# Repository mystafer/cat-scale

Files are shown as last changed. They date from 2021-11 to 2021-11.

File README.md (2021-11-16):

# Arduino Cat Scale

This project performs ongoing scale recordings of a litter box to track when a cat uses it, for how long, and their current weight. The data will hopefully be useful to predict health issues as cats' weight change.  It is designed to work with multiple cats using a custom scale built with Arduino against AWS IoT.

My scale was pretty large (22" x 22") to accomodate a [Litter Robot](https://www.litter-robot.com/), but it should work with a smaller or lighter litter box.

## Basic Arduino-based Scale

The scale is based off [this design I found on Instructables](https://www.instructables.com/Wi-Fi-Smart-Scale-with-ESP8266-Arduino-IDE-Adafrui/).  It utilizes a [Firebeetle 8266 Arduino board](https://www.dfrobot.com/product-1634.html) and a corresponding [LED Cover](https://wiki.dfrobot.com/FireBeetle_Covers-24%C3%978_LED_Matrix).

This project could probably be updated easily to an Espressif 32 / newer chip easily but I tried to stay true to the original Instructable.

In the original Instructable there were links to 3D models that could be printed that would serve as components in the build, but I found them to be too fragile so a I thickened them up a bit [here](3d-models).

My scale looked like this without a cover on it:
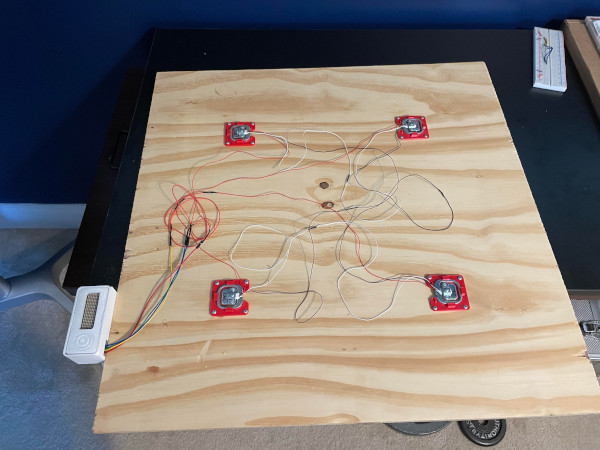
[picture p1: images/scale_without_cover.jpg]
Scale without Cover


I placed another piece of wood on top of this one and then set the scale on top of that.

### Calibration

The scale will send voltage numbers based on HX711 to the Arduino and they need to be converted to either Lbs or Kg. Use the Arduino project [here](arduino/calibrate-scale/calibrate-scale.ino) to do this.  

### Scale Logic

The scale is designed to:

1. wake up and connect to WiFi
2. determine the correct date and time from NTP on the Internet
3. connect to AWS IoT Core to publish measurements and get a shadow configuration
4. when the scale determines that weight has been placed or reset, publish the measurement
5. if the scale sits too long at a non-zero weight it will auto reset

## AWS IoT Core

This project is based on AWS IoT to store the information ultimately in a DynamoDB database.  To do that the secrets.h file needs to be created in the [arduino cat-scale folder](arduino/cat-scale) based on the [AWS secrets template](arduino/secrets.h.template).

The scale can be configured to override defaults using a Shadow named CatScaleConfig.

The scale publishes weight events on MQTT topic `catScale/pub` and listens for messages to reset the scale on `catScale/sub`.

To connect it to AWS IoT, you need an IoT policy and an IoT Thing.  Create the policy similar to the following replacing the AWS account number with your own:

```
{
  "Version": "2012-10-17",
  "Statement": [
    {
      "Effect": "Allow",
      "Action": "iot:Connect",
      "Resource": "arn:aws:iot:us-east-1:<AWS ACCOUNT>:client/Cat-Scale-Firebeetle8266"
    },
    {
      "Effect": "Allow",
      "Action": "iot:Subscribe",
      "Resource": [
        "arn:aws:iot:us-east-1:<AWS ACCOUNT>:topicfilter/catScale/sub",
        "arn:aws:iot:us-east-1:<AWS ACCOUNT>:topicfilter/$aws/things/Cat-Scale-Firebeetle8266/shadow/name/*"
      ]
    },
    {
      "Effect": "Allow",
      "Action": "iot:Receive",
      "Resource": [
        "arn:aws:iot:us-east-1:<AWS ACCOUNT>:topic/catScale/sub",
        "arn:aws:iot:us-east-1:<AWS ACCOUNT>:topic/$aws/things/Cat-Scale-Firebeetle8266/shadow/name/*"
      ]
    },
    {
      "Effect": "Allow",
      "Action": "iot:Publish",
      "Resource": [
        "arn:aws:iot:us-east-1:<AWS ACCOUNT>:topic/catScale/pub",
        "arn:aws:iot:us-east-1:<AWS ACCOUNT>:topic/$aws/things/Cat-Scale-Firebeetle8266/shadow/name/*"
      ]
    }
  ]
}
```

Then create a Thing named `Cat-Scale-Firebeetle8266` and associate the certificate used for it with this policy.  Download the certificates and key from AWS IoT to plug into the `secrets.h` file.

Once this is set up it will begin streaming data to AWS IoT.  

## AWS DynamoDB from IoT Rules

The next step is to get the data to record into a DynamoDB table.  

Create a DynamoDB table named `cat_scale_log` with:

1. Partition Key = `sample_date` as String
2. Search Key = `sample_time` as String

Using AWS IoT rules, create a new rule with the following SQL statement:

`SELECT timestamp() as timestamp, weight, tare FROM 'catScale/pub'`

Add an action to insert into the DynamoDB table `cat_scale_log` with the following settings:

1. Parition Key `sample_date`: `${parse_time("yyyy.MM.dd", timestamp())}`
2. Search Key `sample_time`: `${parse_time("HH:mm:ss.SSS", timestamp())}`
3. Write Message date to: `device_data`

It should look something like this:
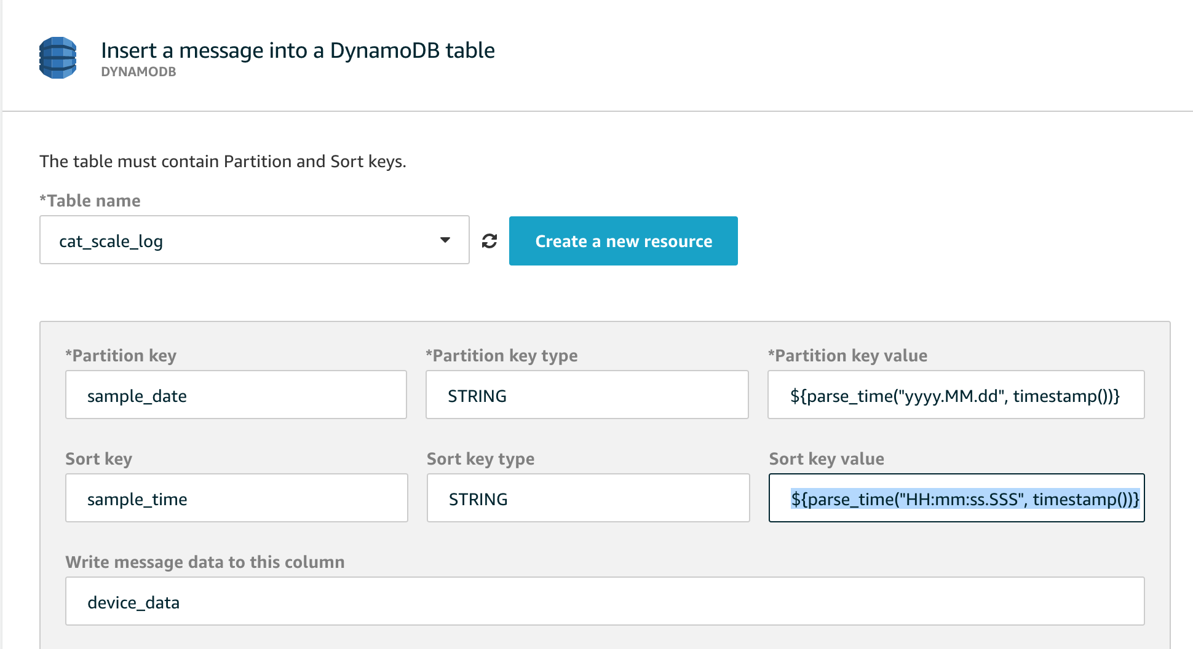
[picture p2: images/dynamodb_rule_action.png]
dynamodb rule action


Data should now be being stored in your table, but it still needs to be manipulated to determine which cat is using the box.

## AWS DynamoDB Stream Lambda Events

Two diffrent python-based lambda functions exist to determine first that an <b>Event</b> has occurred that signifies a cat has used the litter box. Next, it attempts to determine to which cat the event corresponds.

The functions are:

* [Log Scanner](log-scanner-lambda) - creates event records based on logging from scale
* [Event Matcher](event-matcher-lambda) - assigns cats to events

A policy needs to be attached to the functions to allow them to access the DynamoDB tables.

### Log Scanning

A log entry with a recorded weight of zero usually indicates that the scale has reset after a cat has exited the box. If a zero trigger occurs, a lookback of records is performed to determine when the cat entered the box.  The total duration is then calculated in seconds as well as the maximum weight registered during that timeframe.  This is then recorded as a single event record.

The events need a table to be created in DynamoDB named `cat_scale_event` that has the same keys as the log:

1. Partition Key = `sample_date` as String
2. Search Key = `sample_time` as String

### Event Matching

To determine cats for each event, a settings table must be initialized with the basic cat data for each pet that is to be matched.  The table `cat_scale_settings` should be created with teh following schema:

1. Partition Key = `setting_type` as String
2. Search Key = `setting_id` as String

A setting record for each cat should be created

1. `setting_type` = `cat-definition`
2. `setting_id` = a unique logical name for cat record 
3. `defined_weights` as an Array of objects described below
4. `name` as a String - friendly name for cat

`defined_weights` is an array of map objects with only two keys each: `weight`, `timestamp`

The idea is to initialize the `defined_weights` with a zero entry as the initial entry and give room to override the weight if needed in the future in case of a large fluctuation in that cat's weight.

It should look similar to the following in the console for an item:
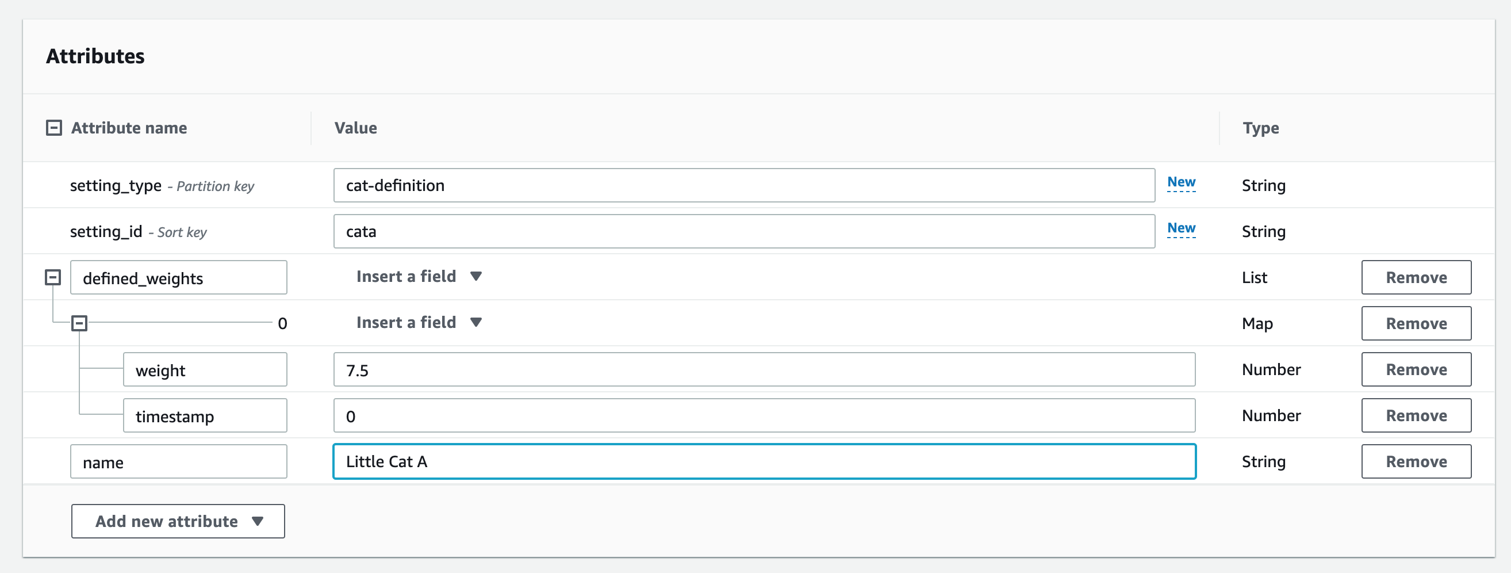
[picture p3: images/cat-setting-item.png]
cat setting item


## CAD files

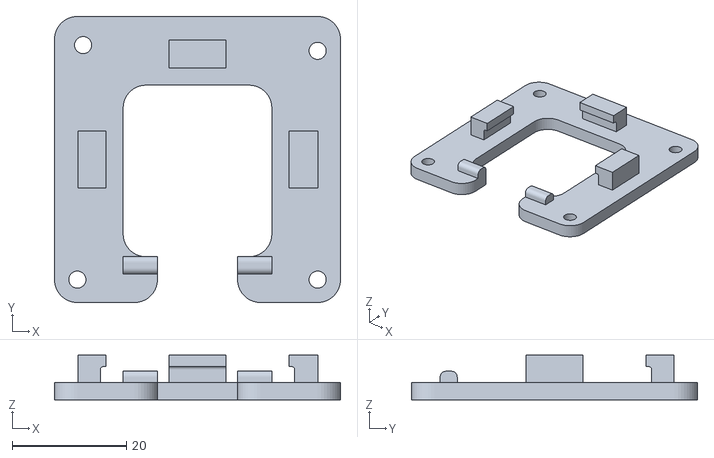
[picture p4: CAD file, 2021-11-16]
3d-models/foot-thickened.stl
50.0 x 50.0 x 7.80

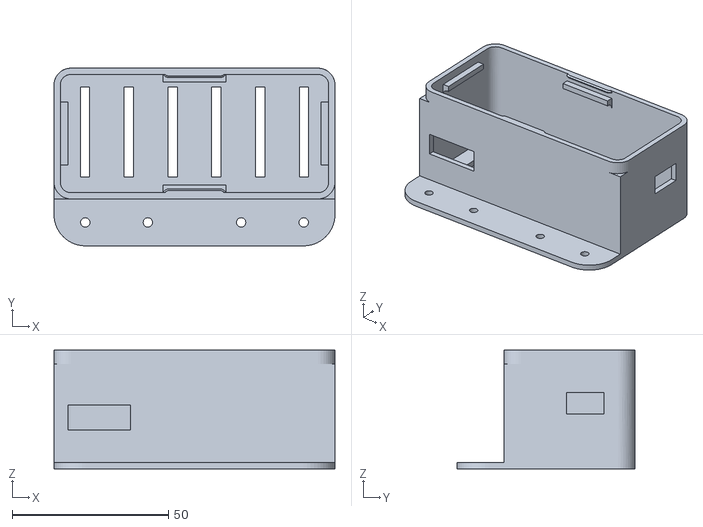
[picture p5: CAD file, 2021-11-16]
3d-models/case.stl
89.8 x 56.8 x 38.0

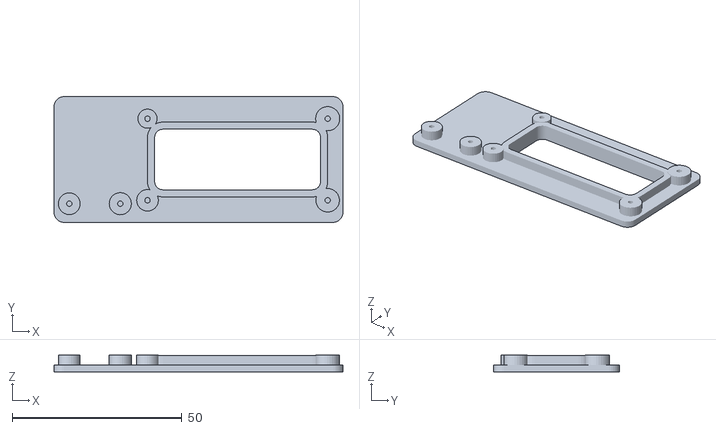
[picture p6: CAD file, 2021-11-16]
3d-models/cover-thickened.stl
85.0 x 37.0 x 5.00

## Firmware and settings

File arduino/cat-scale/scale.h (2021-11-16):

#ifndef scale_h
#define scale_h

#include <Arduino.h>
#include "HX711.h"  // HX711 library for the scale
#include "DFRobot_HT1632C.h" // Library for DFRobot LED matrix display

#define DEFAULT_CALIBRATION_FACTOR -10800.0

#define DOUT 2  // D5  Pin connected to HX711 data output pin
#define CLK  10 // D3  Pin connected to HX711 clk pin

#define DEFAULT_NUM_MEASUREMENTS 10  // Number of measurements
#define DEFAULT_LARGE_THRESHOLD 1.0  // Measures only if the weight is greater than 2 lb
#define DEFAULT_SMALL_THRESHOLD 0.5  // Restart averaging if the weight changes more than 0.5 lb

#define IGNORE_HIGH_THRESHOLD 200.0 // high lbs to ignore above
#define IGNORE_LOW_THRESHOLD  -50.0  // low lbs to ignore below

#define DEFAULT_TARE_HOLD_THRESHOLD 0.25        // retare the scale if the weight is holding steady for tare hold time
#define DEFAULT_TARE_HOLD_TIME 5 * 60 * 1000    // amount of time to wait in ms at a specific value before reseting scale
#define MIN_TARE_HOLD_TIME 15 * 1000            // min amount of time to wait in ms at a specific value before reseting scale

#define DATA 5  // D6 Pin for DFRobot LED matrix display
#define CS   13 // D2 Pin for DFRobot LED matrix display
#define WR   4  // D7 Pin for DFRobot LED matrix display


typedef void (*PublishWeightToAWSFunction)(float weight, bool tare);

#define NEG_INF -1.0 / 0.0

struct ScaleSettings {
  float calibrationFactor = DEFAULT_CALIBRATION_FACTOR;
  int numMeasurements = DEFAULT_NUM_MEASUREMENTS;
  float largeThreshold = DEFAULT_LARGE_THRESHOLD;
  float smallThreshold = DEFAULT_SMALL_THRESHOLD;
  float tareHoldThreshold = DEFAULT_TARE_HOLD_THRESHOLD;
  long tareHoldTime = DEFAULT_TARE_HOLD_TIME;
};

class ScaleManager
{
  private:
    int tareCounter = 0;
    float lastDisplayedValue = NEG_INF;
    DFRobot_HT1632C* ht1632c;
    HX711 scale = HX711();
    PublishWeightToAWSFunction publishWeightToAWS;

    float lastHoldValue = NEG_INF;
    long lastHoldTime = 0;

    
  public:
    ScaleSettings settings;
    
    ScaleManager(DFRobot_HT1632C *ht1632c, PublishWeightToAWSFunction publishWeightToAWS);

    void setup();
    void loop();
    void tareScale();

    void updateSettings(ScaleSettings settings);

  private:
    void displayNumericValueOnLCD(float value);
    bool checkWeightHolding(float weight);
};

#endif

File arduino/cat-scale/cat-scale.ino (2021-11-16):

#define AWS_ENABLED true

#include "scale.h"
#include <ArduinoJson.h>

// set up LED matrix display
DFRobot_HT1632C ht1632c = DFRobot_HT1632C(DATA, WR,CS); 

#if AWS_ENABLED
  #include "AWSIOT.h"
  
  // create AWS IOT connection manager
  void messageHandler(String &topic, String &payload);
  void iotEventListener(int event, const char* msg);
  AWSIOT awsiot = AWSIOT(messageHandler, iotEventListener);
#endif

// create scale manager
void publishWeightToAWS(float weight, bool tare);
ScaleManager scaleMgr = ScaleManager(&ht1632c, publishWeightToAWS);

// keep track of shadow version being processed
int currentShadowVersion = -1;

void setup() {

  // start the serial connection
  Serial.begin(115200);
  delay(2000);
  Serial.println();
  Serial.println();
  
  // setup LED matrix display
  ht1632c.begin();
  ht1632c.isLedOn(true);
  ht1632c.clearScreen();
  delay(500);

  ESP.wdtDisable();
  
  // connect to AWS
  #if AWS_ENABLED
    awsiot.setup();
  #endif
  
  // setup scale
  scaleMgr.setup();
}

void loop() {
  #if AWS_ENABLED
    awsiot.loop();
  #endif
  
  scaleMgr.loop();

  ESP.wdtFeed();
}


void publishWeightToAWS(float weight, bool tare) {
  #if AWS_ENABLED
    awsiot.publishWeightToAWS(weight, tare);
  #endif
}


void processShadowSettings(JsonVariant state, long shadowVersion) {
  if (shadowVersion > currentShadowVersion) {
    
    // make a copy of current settings
    ScaleSettings settings;
    memcpy ( &settings, &(scaleMgr.settings), sizeof(settings) );

    // calibration factor cannot be zero
    float calibrationFactor = state["calibrationFactor"];
    if (calibrationFactor != 0) {
      settings.calibrationFactor = calibrationFactor;
    }

    // number of measurements to take must be greater than 1
    int numMeasurements = state["numMeasurements"];
    if (numMeasurements > 1) {
      settings.numMeasurements = numMeasurements;
    }

    // large threshold must be greater than zero
    float largeThreshold = state["largeThreshold"];
    if (largeThreshold > 0) {
      settings.largeThreshold = largeThreshold;
    }

    // large threshold must be greater than zero and less than large
    float smallThreshold = state["smallThreshold"];
    if (smallThreshold > 0 && smallThreshold < settings.largeThreshold) {
      settings.smallThreshold = smallThreshold;
    }

    // tare hold threshold must be greater than zero
    float tareHoldThreshold = state["tareHoldThreshold"];
    if (tareHoldThreshold > 0) {
      settings.tareHoldThreshold = tareHoldThreshold;
    }

    // tare hold time must be greater than minimum value
    long tareHoldTime = state["tareHoldTime"];
    if (tareHoldTime > MIN_TARE_HOLD_TIME) {
      settings.tareHoldTime = tareHoldTime;
    }
    
    // store currently fetched version
    currentShadowVersion = shadowVersion;

    // update scale settings
    scaleMgr.updateSettings(settings);
    ESP.wdtFeed();
  }  
}

void messageHandler(String &topic, String &payload) {
  ESP.wdtFeed();
  Serial.println("incoming: " + topic + " - " + payload);

  // check which topic is sending data
  if (topic == AWS_IOT_SHADOW_GET_ACCEPTED_SUB) {
    // holds parsed document
    StaticJsonDocument<4096> doc;
  
    // filter for desired information
    StaticJsonDocument<200> filter;
    filter["state"] = true;
    filter["version"] = true;
    filter["state"]["desired"] = true;
    if (deserializeJson(doc, payload, DeserializationOption::Filter(filter)) == DeserializationError::Ok) {
      Serial.println("Get payload");
      serializeJson(doc, Serial);
      Serial.println();

      // retrieve initial settings
      JsonVariant state = doc["state"]["desired"];
      
      // retrieve version
      long shadowVersion = doc["version"];

      processShadowSettings(state, shadowVersion);
    }
  }

  else if (topic == AWS_IOT_SHADOW_UPDATE_DELTA_SUB) {
    // holds parsed document
    StaticJsonDocument<4096> doc;
  
    // filter for desired information
    StaticJsonDocument<200> filter;
    filter["state"] = true;
    filter["version"] = true;
    if (deserializeJson(doc, payload, DeserializationOption::Filter(filter)) == DeserializationError::Ok) {
      Serial.println("Delta payload");
      serializeJson(doc, Serial);
      Serial.println();

      // retrieve initial settings
      JsonVariant state = doc["state"];
      
      // retrieve version
      long shadowVersion = doc["version"];

      processShadowSettings(state, shadowVersion);
    }
  }

  // anything send on subscribe topic will tare the scale
  else if (topic == AWS_IOT_SUBSCRIBE_TOPIC) {
    Serial.println("Reset message received");
    ht1632c.print("tare...", 50);
    ESP.wdtFeed();
    scaleMgr.tareScale();
  }
}

void iotEventListener(int event, const char* msg) {
  if (strlen(msg) > 5) {
    ht1632c.print(msg, 50);
  }
  else {
    ht1632c.clearScreen();
    ht1632c.print(msg);
  }
}

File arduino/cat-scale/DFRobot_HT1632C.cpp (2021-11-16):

/*!
 * @file DFRobot_HT1632.cpp
 * @brief DFRobot's DFRobot_HT1632C
 * @n DFRobot's LED matrix driver;
 *
 * @copyright	[DFRobot](http://www.dfrobot.com), 2016
 * @copyright	GNU Lesser General Public License
 *
 * @author [yuxiang](1137717512@qq.com)
 * @version  V1.0
 * @date  2017-03-30
 */
#include "DFRobot_HT1632C.h"
#include <math.h>
#include <stdio.h>
#include <stdlib.h>

#define min _min
#define max _max

/*
const byte FONT_5X4 [] PROGMEM = {
    0b00000000,  //  
    0b11101000,  // !
    0b11000000, 0b00000000, 0b11000000,  // "
    0b01010000, 0b11111000, 0b01010000, 0b11111000, 0b01010000,  // #
    0b00000000, 0b00000000, 0b00000000, 0b00000000,  // $
    0b11001000, 0b11010000, 0b00100000, 0b01011000, 0b10011000,  // %
    0b01010000, 0b10101000, 0b10011000, 0b01011000,  // &
    0b11000000,  // '
    0b01110000, 0b10001000,  // (
    0b10001000, 0b01110000,  // )
    0b10100000, 0b01000000, 0b10100000,  // *
    0b00100000, 0b00100000, 0b11111000, 0b00100000, 0b00100000,  // +
    0b00001000, 0b00010000,  // ,
    0b00100000, 0b00100000, 0b00100000,  // -
    0b00001000,  // .
    0b00001000, 0b00110000, 0b01100000, 0b10000000,  // /
    0b01110000, 0b10001000, 0b01110000,  // 0
    0b01001000, 0b11111000, 0b00001000,  // 1
    0b01001000, 0b10011000, 0b10101000, 0b01001000,  // 2
    0b10101000, 0b10101000, 0b01010000,  // 3
    0b00110000, 0b01010000, 0b11111000, 0b00010000,  // 4
    0b11101000, 0b10101000, 0b10110000,  // 5
    0b01110000, 0b10101000, 0b10101000, 0b00010000,  // 6
    0b10000000, 0b10111000, 0b10100000, 0b11000000,  // 7
    0b01010000, 0b10101000, 0b10101000, 0b01010000,  // 8
    0b01000000, 0b10100000, 0b10101000, 0b01110000,  // 9
    0b01010000,  // :
    0b00001000, 0b01010000,  // ;
    0b00100000, 0b01010000, 0b10001000,  // <
    0b01010000, 0b01010000, 0b01010000,  // =
    0b10001000, 0b01010000, 0b00100000,  // >
    0b01000000, 0b10000000, 0b10011000, 0b01100000,  // ?
    0b01110000, 0b10000000, 0b10110000, 0b10101000, 0b11110000,  // @
    0b01111000, 0b10100000, 0b10100000, 0b01111000,  // A
    0b11111000, 0b10101000, 0b01010000,  // B
    0b01110000, 0b10001000, 0b10001000, 0b01010000,  // C
    0b11111000, 0b10001000, 0b01110000,  // D
    0b11111000, 0b10101000, 0b10001000,  // E
    0b11111000, 0b10100000, 0b10100000,  // F
    0b01110000, 0b10001000, 0b10011000, 0b01010000,  // G
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
};

int FONT_5X4_END [] = {
    1,   2,   5,  10,  14,  19,  23,  24,
   26,  28,  31,  36,  38,  41,  42,  46,
   49,  52,  56,  59,  63,  66,  70,  74,
   78,  82,  83,  85,  88,  91,  94,  98,
  103, 107, 110, 114, 117, 120, 123, 127,
  131, 134, 137, 141, 144, 149, 154, 158,
  161, 166, 169, 173, 176, 180, 185, 190,
  193, 196, 200, 202, 206, 208, 211, 214
};
*/
const byte FONT_8X4 [] PROGMEM = {
  0b00000000,                                                   // SPACE   1
  0b01110000, 0b11111101, 0b01110000,                           // !			 4
  0b11000000, 0b00000000, 0b11000000,                           // "				7
  0b00100100, 0b11111111, 0b00100100, 0b11111111, 0b00100100,   // #				12
  0b00100100, 0b01010010, 0b11011011, 0b01001010, 0b00100100,   // $				17
  0b11000001, 0b11000110, 0b00011000, 0b01100011, 0b10000011,   // %				22
  0b01101110, 0b10010001, 0b10010010, 0b01100101,               // &				26
  0b11000000,                                                   // '				27
  0b00111100, 0b01000010, 0b10000001,                           // (				30
  0b10000001, 0b01000010, 0b00111100,                           // )				33
  0b10100000, 0b01000000, 0b10100000,                           // *				36
  0b00001000, 0b00001000, 0b00111110, 0b00001000, 0b00001000,   // +				41
  0b00000001, 0b00000010,                                       // ,				43
  0b00001000, 0b00001000, 0b00001000,                           // -				46
  0b00000001,                                                   // .				47
  0b00000011, 0b00001100, 0b00110000, 0b11000000,               /* / */
  0b01111110, 0b10110001, 0b10001101, 0b01111110,               // 0
  0b01000001, 0b11111111, 0b00000001,                           // 1
  0b01000011, 0b10000101, 0b10001001, 0b01110001,               // 2
  0b01000010, 0b10001001, 0b10001001, 0b01110110,               // 3
  0b00011100, 0b00100100, 0b01001111, 0b10000100,               // 4
  0b11110001, 0b10010001, 0b10010001, 0b10001110,               // 5
  0b01111110, 0b10001001, 0b10001001, 0b01000110,               // 6
  0b10000000, 0b10000111, 0b10011000, 0b11100000,               // 7
  0b01110110, 0b10001001, 0b10001001, 0b01110110,               // 8
  0b01110010, 0b10001001, 0b10001001, 0b01111110,               // 9
  0b00100010,                                                   // :
  0b00000001, 0b00100010,                                       // ;
  0b00011000, 0b00100100, 0b01000010, 0b10000001,               // <
  0b00010100, 0b00010100, 0b00010100, 0b00010100,               // =
  0b10000001, 0b01000010, 0b00100100, 0b00011000,               // >
  0b01000000, 0b10001101, 0b10001000, 0b01110000,               // ?
  0b01111110, 0b10000001, 0b10111001, 0b10000101, 0b01111100,   // @
  0b01111111, 0b10001000, 0b10001000, 0b01111111,               // A
  0b11111111, 0b10001001, 0b10001001, 0b01110110,               // B
  0b01111110, 0b10000001, 0b10000001, 0b01000010,               // C
  0b11111111, 0b10000001, 0b10000001, 0b01111110,               // D
  0b11111111, 0b10001001, 0b10001001, 0b10000001,               // E
  0b11111111, 0b10010000, 0b10010000, 0b10000000,               // F
  0b01111110, 0b10000001, 0b10001001, 0b01001110,               // G
  0b11111111, 0b00001000, 0b00001000, 0b11111111,               // H
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
};

int FONT_8X4_END [] = {
       1,   4,   7,  12,  17,  22,  26,  27,
      30,  33,  36,  41,  43,  46,  47,  51,
      55,  58,  62,  66,  70,  74,  78,  82,
      86,  90,  91,  93,  97, 101, 105, 109,
     114, 118, 122, 126, 130, 134, 138, 142,
     146, 149, 153, 157, 161, 166, 171, 175,
     179, 184, 188, 192, 195, 199, 203, 208,
     213, 218, 222, 224, 228, 230, 233, 237
};

DFRobot_HT1632C::DFRobot_HT1632C(uint8_t data, uint8_t wr, uint8_t RD, uint8_t cs){
	data_t = data;
	cs_t = cs;
	wr_t = wr;
	rd_t = rd_t;
	
	for(uint8_t i=0; i < 24; i++){
		matrix[i] = 0;
	}
	matrix[0] = 0x40;
}

DFRobot_HT1632C::DFRobot_HT1632C(uint8_t data, uint8_t wr, uint8_t cs){
	data_t = data;
	cs_t = cs;
	wr_t = wr;
	
	for(uint8_t i=0; i < 24; i++){
		matrix[i] = 0;
	}
	matrix[0] = 0x40;
}
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
